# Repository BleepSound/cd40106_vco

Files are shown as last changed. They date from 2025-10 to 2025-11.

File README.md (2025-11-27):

[][cc-by-sa]

# CD40106 VCO

Latest documentation available at https://bleepsound.github.io/modules/

[][cc-by-sa]

[cc-by-sa]: http://creativecommons.org/licenses/by-sa/4.0/
[cc-by-sa-image]: https://licensebuttons.net/l/by-sa/4.0/88x31.png
[cc-by-sa-shield]: https://img.shields.io/badge/License-CC%20BY--SA%204.0-lightgrey.svg

[][cc-by-sa]

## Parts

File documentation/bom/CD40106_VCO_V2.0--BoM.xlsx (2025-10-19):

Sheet: BoM
CD40106_VCO_V2.0 Bill of Materials
Schematic: | CD40106_VCO | Component Groups: | 57
Variant: | default | Component Count: | 118 (1 SMD/ 117 THT)
Revision: | 2.0 | Fitted Components: | 118 (1 SMD/ 117 THT)
Date: | 2025-10-18 | Number of PCBs: | 1
KiCad Version: | 9.0.4-9.0.4-0~ubuntu22.04.1 | Total Components: | 118
Row | Description | References | Value | Quantity Per PCB | Links | Comments
1 | Multilayer Monolithic Ceramic capacitor 50V 10% | C1 | 470pF | 1 | https://www.taydaelectronics.com/capacitors/monolithic-ceramic-capacitor.html
2 | Multilayer Monolithic Ceramic capacitor 50V 10% | C6 C7 | 1nF | 2 | https://www.taydaelectronics.com/capacitors/monolithic-ceramic-capacitor.html
3 | 100V 5% Mylar Film Capacitors | C2 | 2.2nF | 1 | https://www.taydaelectronics.com/capacitors/2-2nf-0-0022uf-100v-5-mylar-film-capacitors.html | If you don't have a mylar capacitor, just use a regular ceramic one
4 | Multilayer Monolithic Ceramic capacitor 50V 10% | C23 | 2.2nF | 1 | https://www.taydaelectronics.com/capacitors/monolithic-ceramic-capacitor.html
5 | Multilayer Monolithic Ceramic capacitor 50V 10% | C4 C5 C12 C13 C14 C15 C16 C17 C18 C19 C20 C21 C22 | 100nF | 13 | https://www.taydaelectronics.com/capacitors/monolithic-ceramic-capacitor.html
6 | Multilayer Monolithic Ceramic capacitor 50V 10% | C3 C8 C9 | 1uF | 3 | https://www.taydaelectronics.com/capacitors/monolithic-ceramic-capacitor.html
7 | 10uF Electrolytic capacitor, 2.0mm pitch, 5mm diameter | C10 C11 | 10uF | 2 | https://www.taydaelectronics.com/capacitors/electrolytic-capacitors.html
8 | Switching Signal Diode 200mA 100V DO-35 | D1 D2 | 1N4148 | 2 | https://www.taydaelectronics.com/1n4148-switching-signal-diode.html
9 | 40V 1A Schottky Barrier Rectifier Diode, DO-41 | D6 D8 | 1N5819 (http://www.vishay.com/docs/88525/1n5817.pdf) | 2 | https://www.taydaelectronics.com/1n5819-schottky-barrier-diode-1a-40v.html
10 | Small Signal Diode 200mA 100V DO-35 | D3 D4 | 1N914 | 2 | https://www.taydaelectronics.com/1n914-small-signal-diode-200ma-100v.html
11 | Alpha/bourns vertical potentiometer | FM_LVL1 | B1M | 1 | https://www.thonk.co.uk/shop/alpha-9mm-pots/
12 | Alpha/bourns vertical potentiometer | Fine1 | B10k | 1 | https://www.thonk.co.uk/shop/alpha-9mm-pots/
13 | Thonkiconn jack | J2 | CV | 1 | https://www.thonk.co.uk/shop/thonkiconn/
14 | 2.54mm pitch pin header vertical 1x2pos | J14 | Conn_01x02 | 1
15 | 2.54mm pitch pin header vertical 1x4pos | J11 | Conn_01x04 | 1
16 | 2.54mm pitch pin socket vertical 1x4pos | J12 | Conn_01x04 | 1
17 | 2.54mm pitch pin socket vertical 1x8pos | J5 J7 | Conn_Circuit | 2
18 | 2.54mm pitch pin header vertical 1x8pos | J6 J8 | Conn_Jack | 2
19 | Thonkiconn jack | J1 | FM | 1 | https://www.thonk.co.uk/shop/thonkiconn/
20 | Thonkiconn jack | J4 | PWM_CV | 1 | https://www.thonk.co.uk/shop/thonkiconn/
21 | Eurorack 10 pin shrouded power header IDC | J16 | Power Input | 1 | https://www.thonk.co.uk/shop/eurorack-diy-essentials/
22 | Thonkiconn jack | J9 | Saw | 1 | https://www.thonk.co.uk/shop/thonkiconn/
23 | Thonkiconn jack | J13 | Sine | 1 | https://www.thonk.co.uk/shop/thonkiconn/
24 | Thonkiconn jack | J10 | Square | 1 | https://www.thonk.co.uk/shop/thonkiconn/
25 | Thonkiconn jack | J3 | Sync | 1 | https://www.thonk.co.uk/shop/thonkiconn/
26 | Thonkiconn jack | J15 | Tri | 1 | https://www.thonk.co.uk/shop/thonkiconn/
27 | Alpha/bourns vertical potentiometer | PWM1 | B100k | 1 | https://www.thonk.co.uk/shop/alpha-9mm-pots/
28 | Alpha/bourns vertical potentiometer | PWM_CV_LVL1 | B250k | 1 | https://www.thonk.co.uk/shop/alpha-9mm-pots/
29 | BC548 NPN General Purpose Transistor | Q2 Q3 | BC548 (https://www.onsemi.com/pub/Collateral/BC550-D.pdf) | 2 | https://www.taydaelectronics.com/bc548-transistor-npn-30v-0-1a.html
30 | BC558 PNP General Purpose Transistor | Q1 Q4 | BC558 (https://www.onsemi.com/pub/Collateral/BC556BTA-D.pdf) | 2 | https://www.taydaelectronics.com/bc558-bc558b-transistor-pnp-0-1a-30v.html
31 | 2.5mm*6.8mm 1/4W 1% Metal film resistor | R15 R29 R36 R41 R44 | 1k | 5 | https://www.taydaelectronics.com/resistors/1-4w-metal-film-resistors/test-group-2.html
32 | 2.5mm*6.8mm 1/4W 1% Metal film resistor | R5 | 1k5 | 1 | https://www.taydaelectronics.com/resistors/1-4w-metal-film-resistors/test-group-2.html
33 | 2.5mm*6.8mm 1/4W 1% Metal film resistor | R47 | 2.2k | 1 | https://www.taydaelectronics.com/resistors/1-4w-metal-film-resistors/test-group-2.html
34 | 2.5mm*6.8mm 1/4W 1% Metal film resistor | R16 R17 R35 | 4.7k | 3 | https://www.taydaelectronics.com/resistors/1-4w-metal-film-resistors/test-group-2.html
35 | 2.5mm*6.8mm 1/4W 1% Metal film resistor | R24 | 9k1 | 1 | https://www.taydaelectronics.com/resistors/1-4w-metal-film-resistors/test-group-2.html
36 | 2.5mm*6.8mm 1/4W 1% Metal film resistor | R20 R21 R22 R23 R25 R26 R34 R37 R48 | 10k | 9 | https://www.taydaelectronics.com/resistors/1-4w-metal-film-resistors/test-group-2.html
37 | 2.5mm*6.8mm 1/4W 1% Metal film resistor | R10 | 14k | 1 | https://www.taydaelectronics.com/resistors/1-4w-metal-film-resistors/test-group-2.html
38 | 2.5mm*6.8mm 1/4W 1% Metal film resistor | R28 R38 R43 R45 | 20k | 4 | https://www.taydaelectronics.com/resistors/1-4w-metal-film-resistors/test-group-2.html
39 | 2.5mm*6.8mm 1/4W 1% Metal film resistor | R18 R19 R40 | 33k | 3 | https://www.taydaelectronics.com/resistors/1-4w-metal-film-resistors/test-group-2.html
40 | 2.5mm*6.8mm 1/4W 1% Metal film resistor | R11 R46 | 47k | 2 | https://www.taydaelectronics.com/resistors/1-4w-metal-film-resistors/test-group-2.html
41 | 2.5mm*6.8mm 1/4W 1% Metal film resistor | R9 R14 | 68k | 2 | https://www.taydaelectronics.com/resistors/1-4w-metal-film-resistors/test-group-2.html
42 | 2.5mm*6.8mm 1/4W 1% Metal film resistor | R1 R2 R3 R4 R7 R8 R12 R13 R31 R42 | 100k | 10 | https://www.taydaelectronics.com/resistors/1-4w-metal-film-resistors/test-group-2.html
43 | 2.5mm*6.8mm 1/4W 1% Metal film resistor | R33 | 130k | 1 | https://www.taydaelectronics.com/resistors/1-4w-metal-film-resistors/test-group-2.html
44 | 2.5mm*6.8mm 1/4W 1% Metal film resistor | R30 R39 | 330k | 2 | https://www.taydaelectronics.com/resistors/1-4w-metal-film-resistors/test-group-2.html
45 | 2.5mm*6.8mm 1/4W 1% Metal film resistor | R27 | 470k | 1 | https://www.taydaelectronics.com/resistors/1-4w-metal-film-resistors/test-group-2.html
46 | 2.5mm*6.8mm 1/4W 1% Metal film resistor | R6 R32 | 1M | 2 | https://www.taydaelectronics.com/resistors/1-4w-metal-film-resistors/test-group-2.html
47 | 6 Position DPST Rotary Switch | SW1 | Octave select switch (https://fr.rs-online.com/web/p/commutateurs-rotatifs/8660278) | 1 | https://uk.rs-online.com/web/p/rotary-switches/8660278?searchId=ac79d3c7-8ed3-428a-a94f-85e7c88d4e39&gb=s | Cut the shaft to required length
48 | Trimmer potentiometer, 25 turn series 3296W | Sine_Bias_trim1 Sine_Shape_trim1 | 100k (https://www.taydaelectronics.com/potentiometer-variable-resistors/cermet-potentiometers/3296w/100k-ohm-trimmer-potentiometer-cermet-25-turns-3296w.html) | 2 | https://www.thonk.co.uk/shop/25-turn-trimmer-potentiometer/
49 | Trimmer potentiometer, 25 turn series 3296W | Sine_Lvl_trim1 | 1M (https://www.taydaelectronics.com/potentiometer-variable-resistors/cermet-potentiometers/3296w/1m-ohm-trimmer-potentiometer-cermet-25-turns-3296w.html) | 1 | https://www.thonk.co.uk/shop/25-turn-trimmer-potentiometer/
50 | 10K NTC type Thermistor | TH1 TH2 TH3 TH4 | Thermistor_NTC - 10k (https://www.taydaelectronics.com/thermistors/10k-ohm-ntc-thermistor-5mm.html) | 4 | https://www.taydaelectronics.com/10k-ohm-ntc-thermistor-5mm.html
51 | Inverters Hex Schmitt Trigger | U2 | CD40106 (https://assets.nexperia.com/documents/data-sheet/HEF40106B.pdf) | 1 | https://eu.mouser.com/ProductDetail/Texas-Instruments/CD40106BE?qs=YhsVCygOPE1CyKyInx%252Bh3Q%3D%3D
52 | Dual Transconductance Amplifiers | U6 | LM13700 (http://www.ti.com/lit/ds/symlink/lm13700.pdf) | 1 | https://eu.mouser.com/c/semiconductors/amplifier-ics/transconductance-amplifiers/?series=LM13700
53 | Adjustable Micropower Voltage Reference Diodes, TO-92 | U3 | LM336-2.5 (http://www.ti.com/lit/ds/symlink/lm185-adj.pdf) | 1 | https://uk.rs-online.com/web/p/voltage-references/5335799P?gb=s
54 | Operational Amplifiers - Op Amps Dual JFET In Low N | U4 U5 | TL072 (http://www.ti.com/lit/ds/symlink/tl071.pdf) | 2 | https://eu.mouser.com/ProductDetail/Texas-Instruments/TL072IP?qs=5BZzbFV4k2v7IBrcArRPQw%3D%3D
55 | Quad Op-Amp | U1 U7 | TL074 (http://www.ti.com/lit/ds/symlink/tl071.pdf) | 2 | https://www.thonk.co.uk/shop/eurorack-diy-essentials/
56 | Trimmer potentiometer, 25 turn series 3296W | lvl_Trim1 | 1k | 1 | https://www.thonk.co.uk/shop/25-turn-trimmer-potentiometer/
57 | Trimmer potentiometer, 25 turn series 3296W | lvl_Trim2 | 2k | 1 | https://www.thonk.co.uk/shop/25-turn-trimmer-potentiometer/

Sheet: Colors
Columns colors
KiCad Fields (default)
Generated Fields
User Fields
Empty Fields

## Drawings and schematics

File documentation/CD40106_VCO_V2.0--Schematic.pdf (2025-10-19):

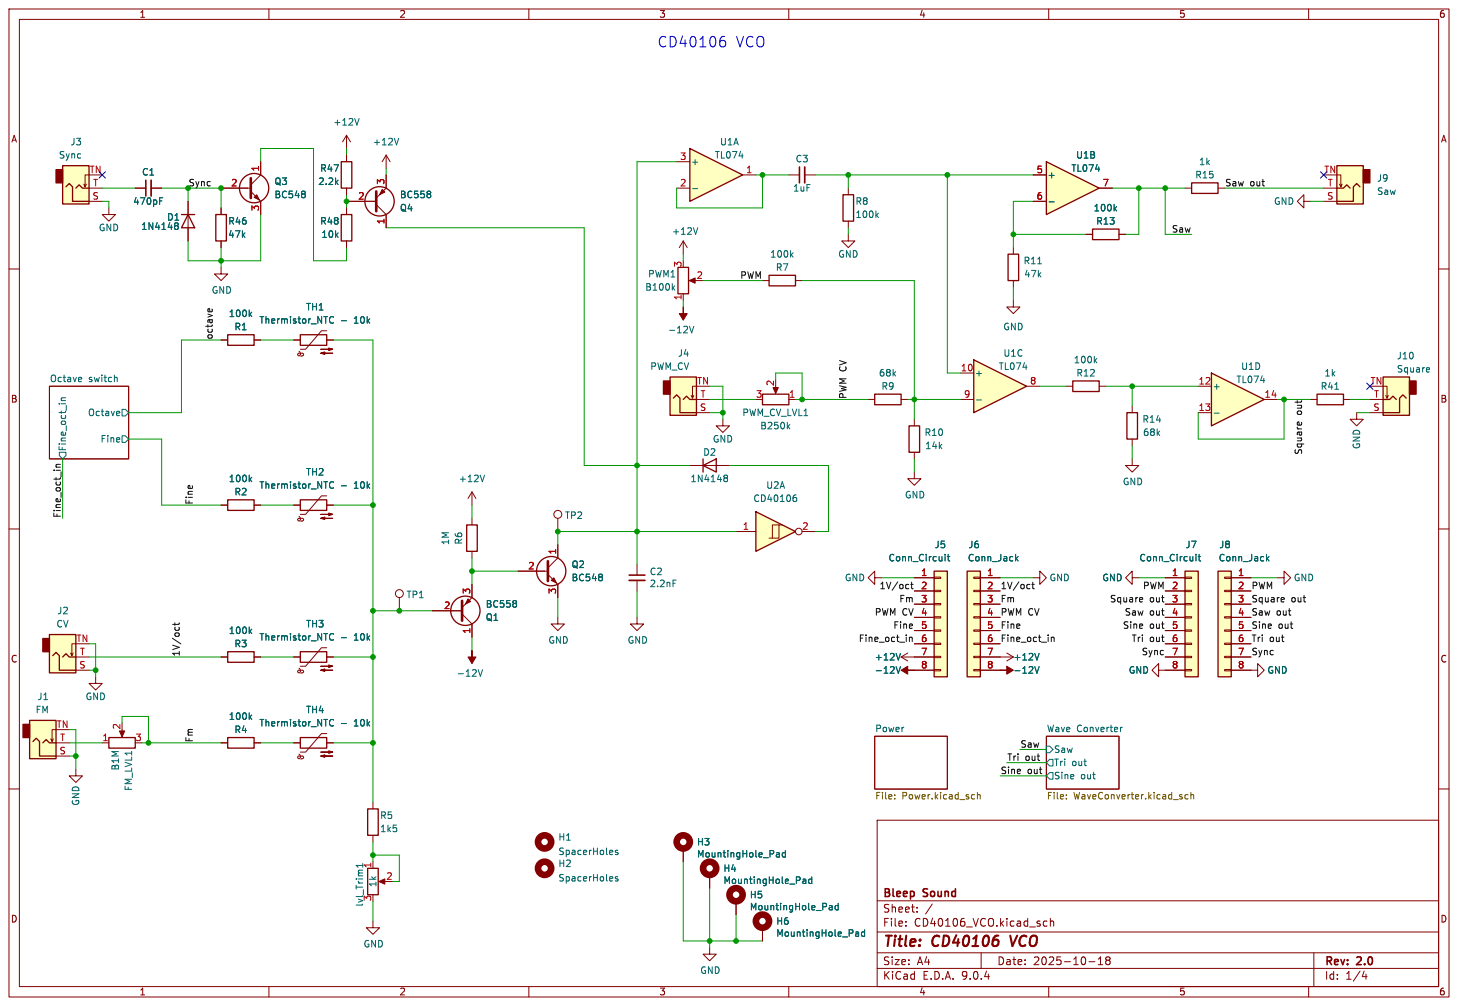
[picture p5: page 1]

Sine out Tri out Saw PWM CV octave

Square outSquare out Fm

Tri out Sine out Wave Converter File: WaveConverter.kicad_sch +12V GND

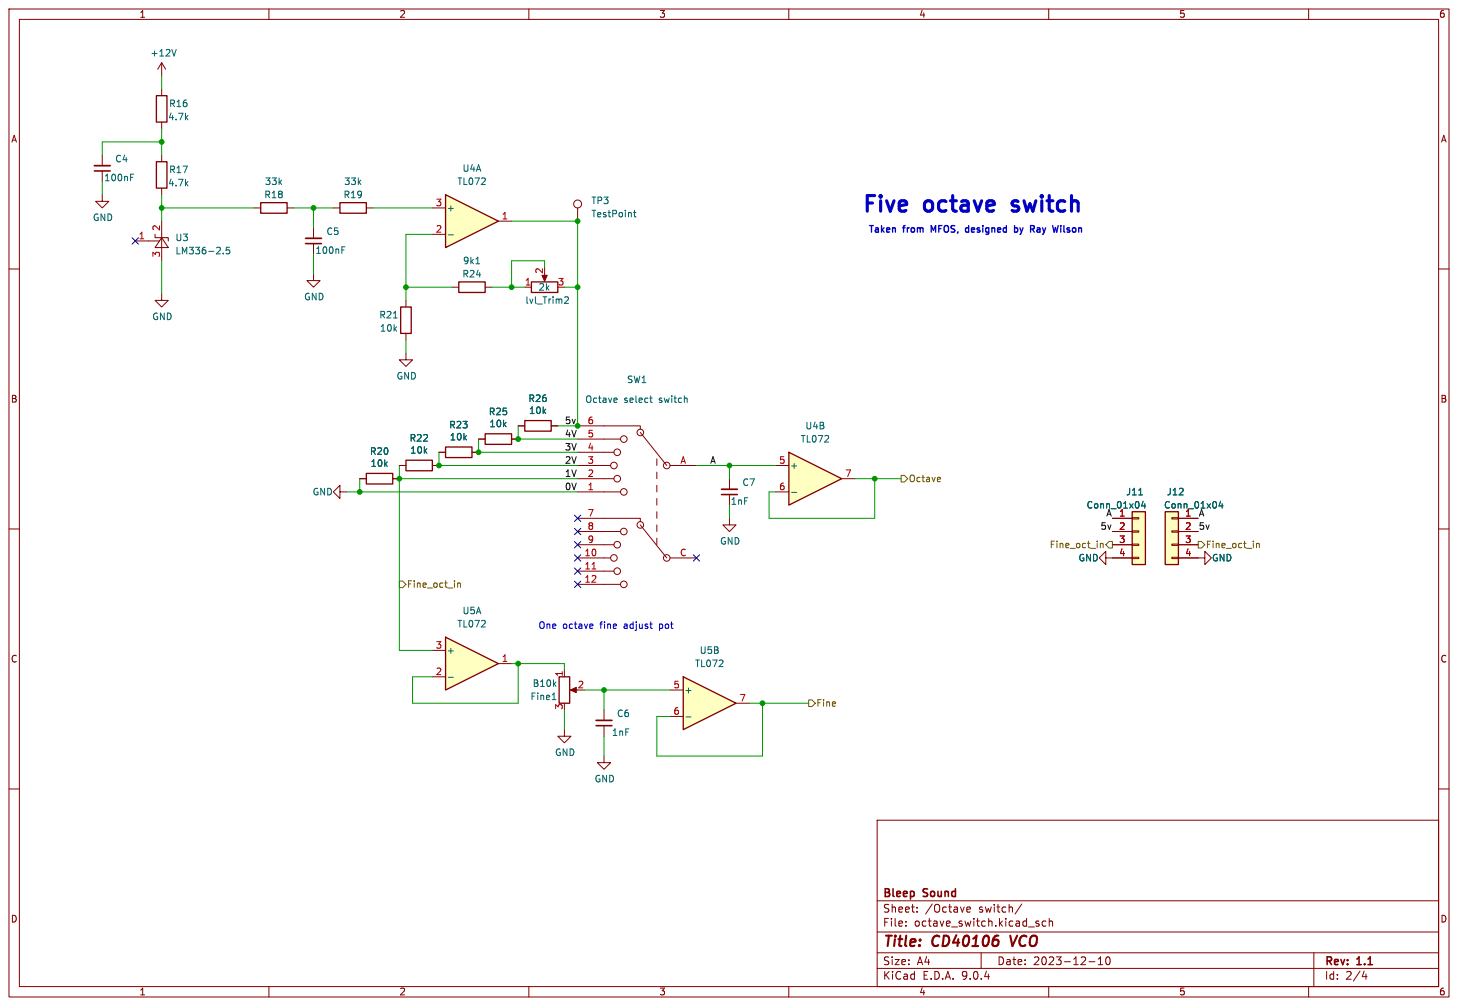
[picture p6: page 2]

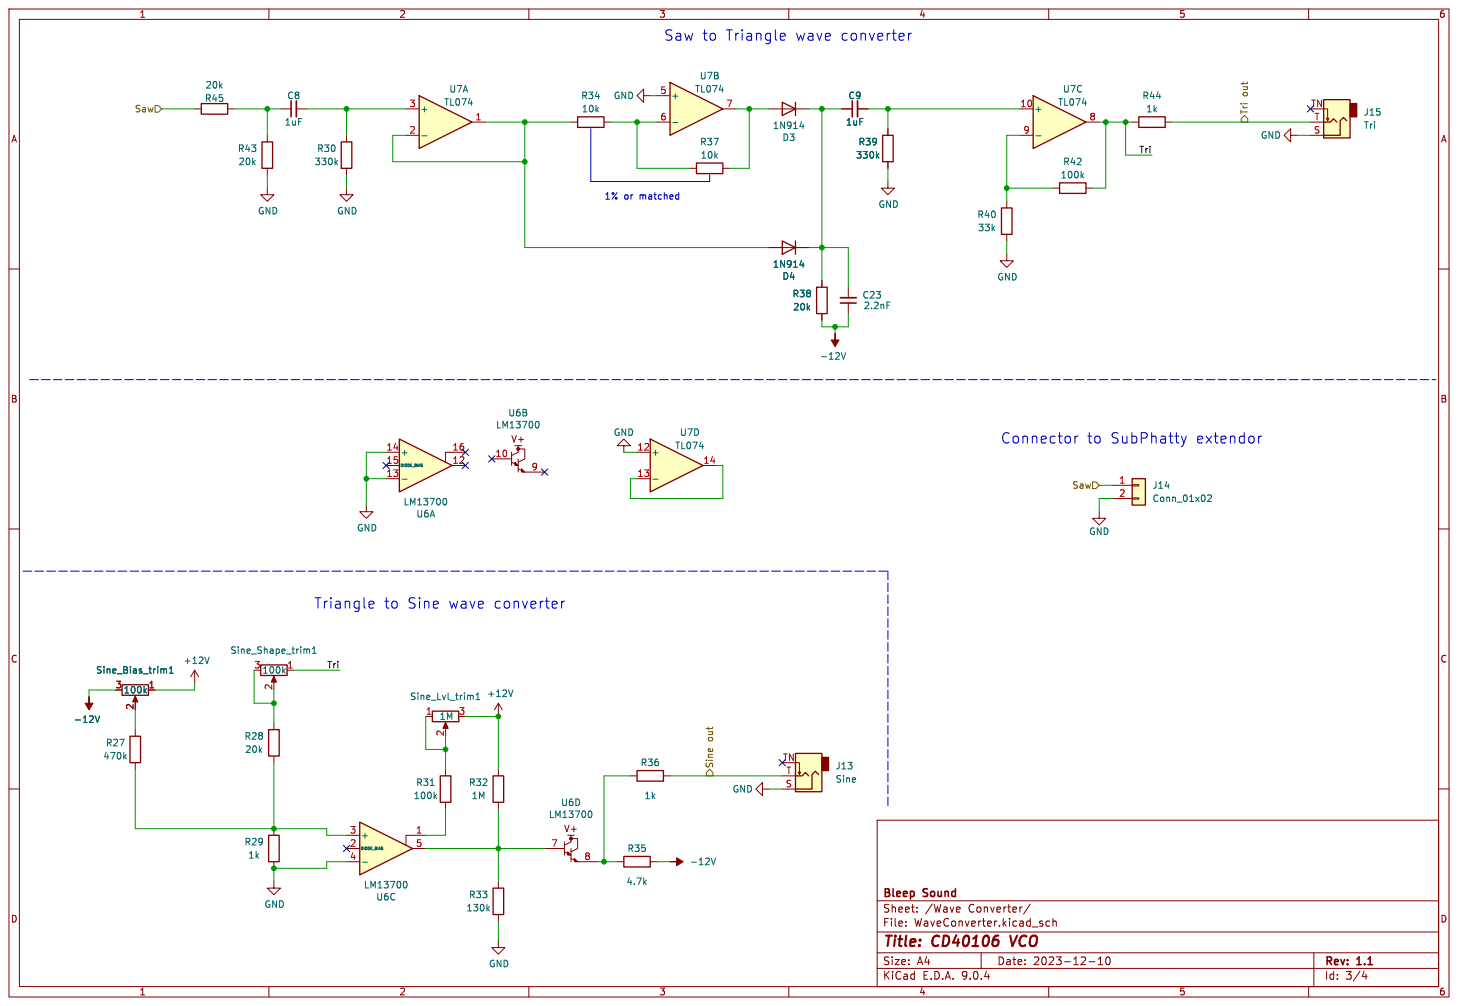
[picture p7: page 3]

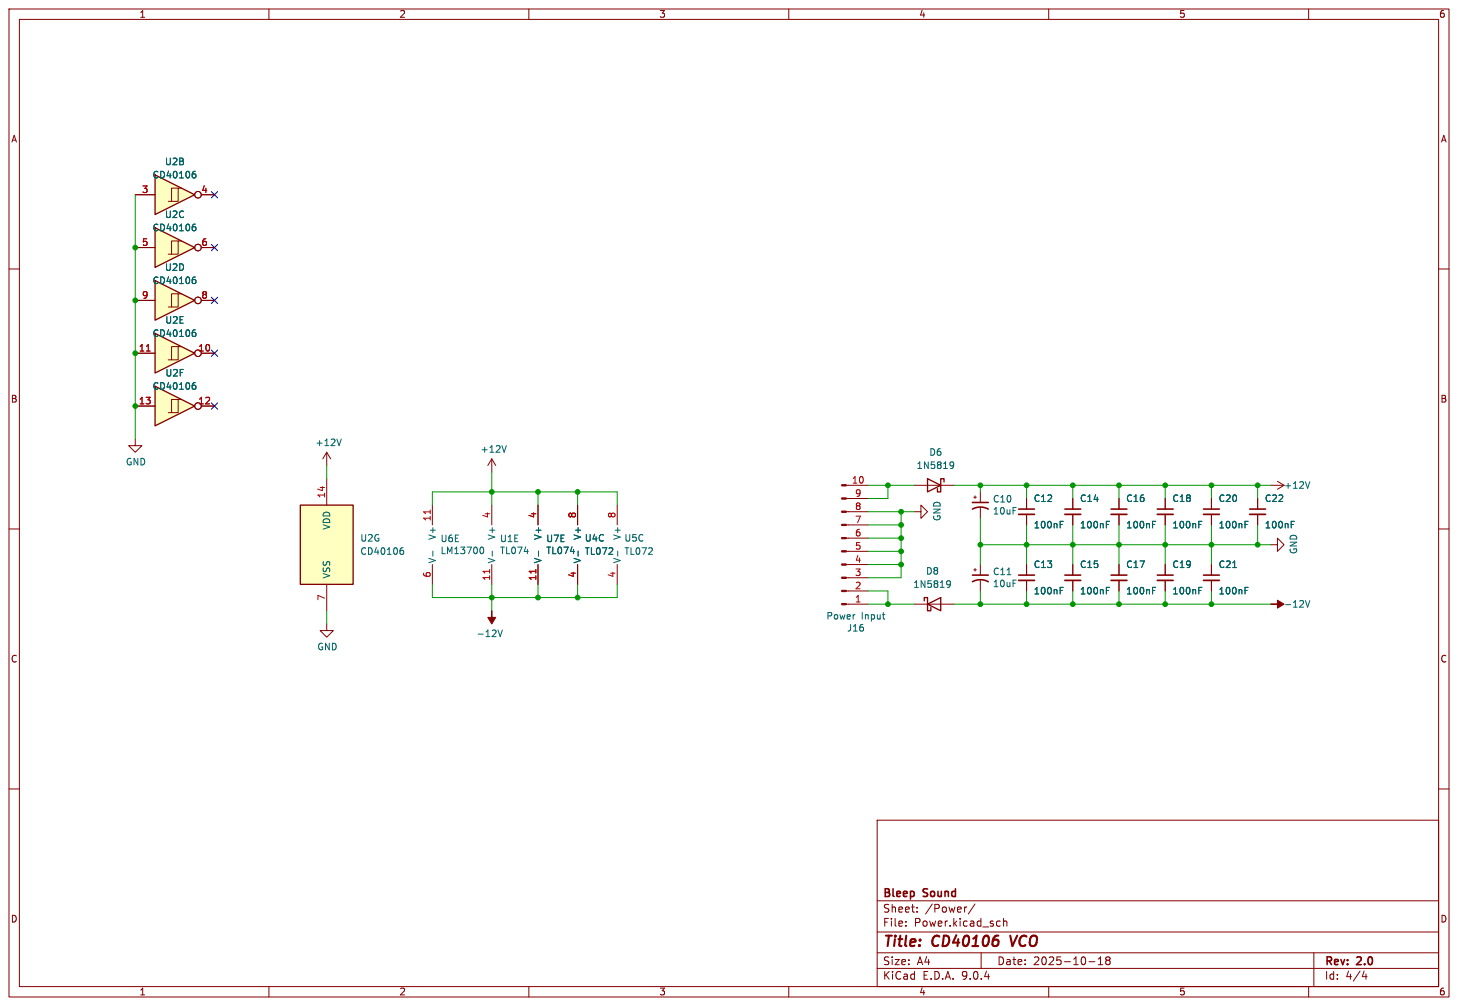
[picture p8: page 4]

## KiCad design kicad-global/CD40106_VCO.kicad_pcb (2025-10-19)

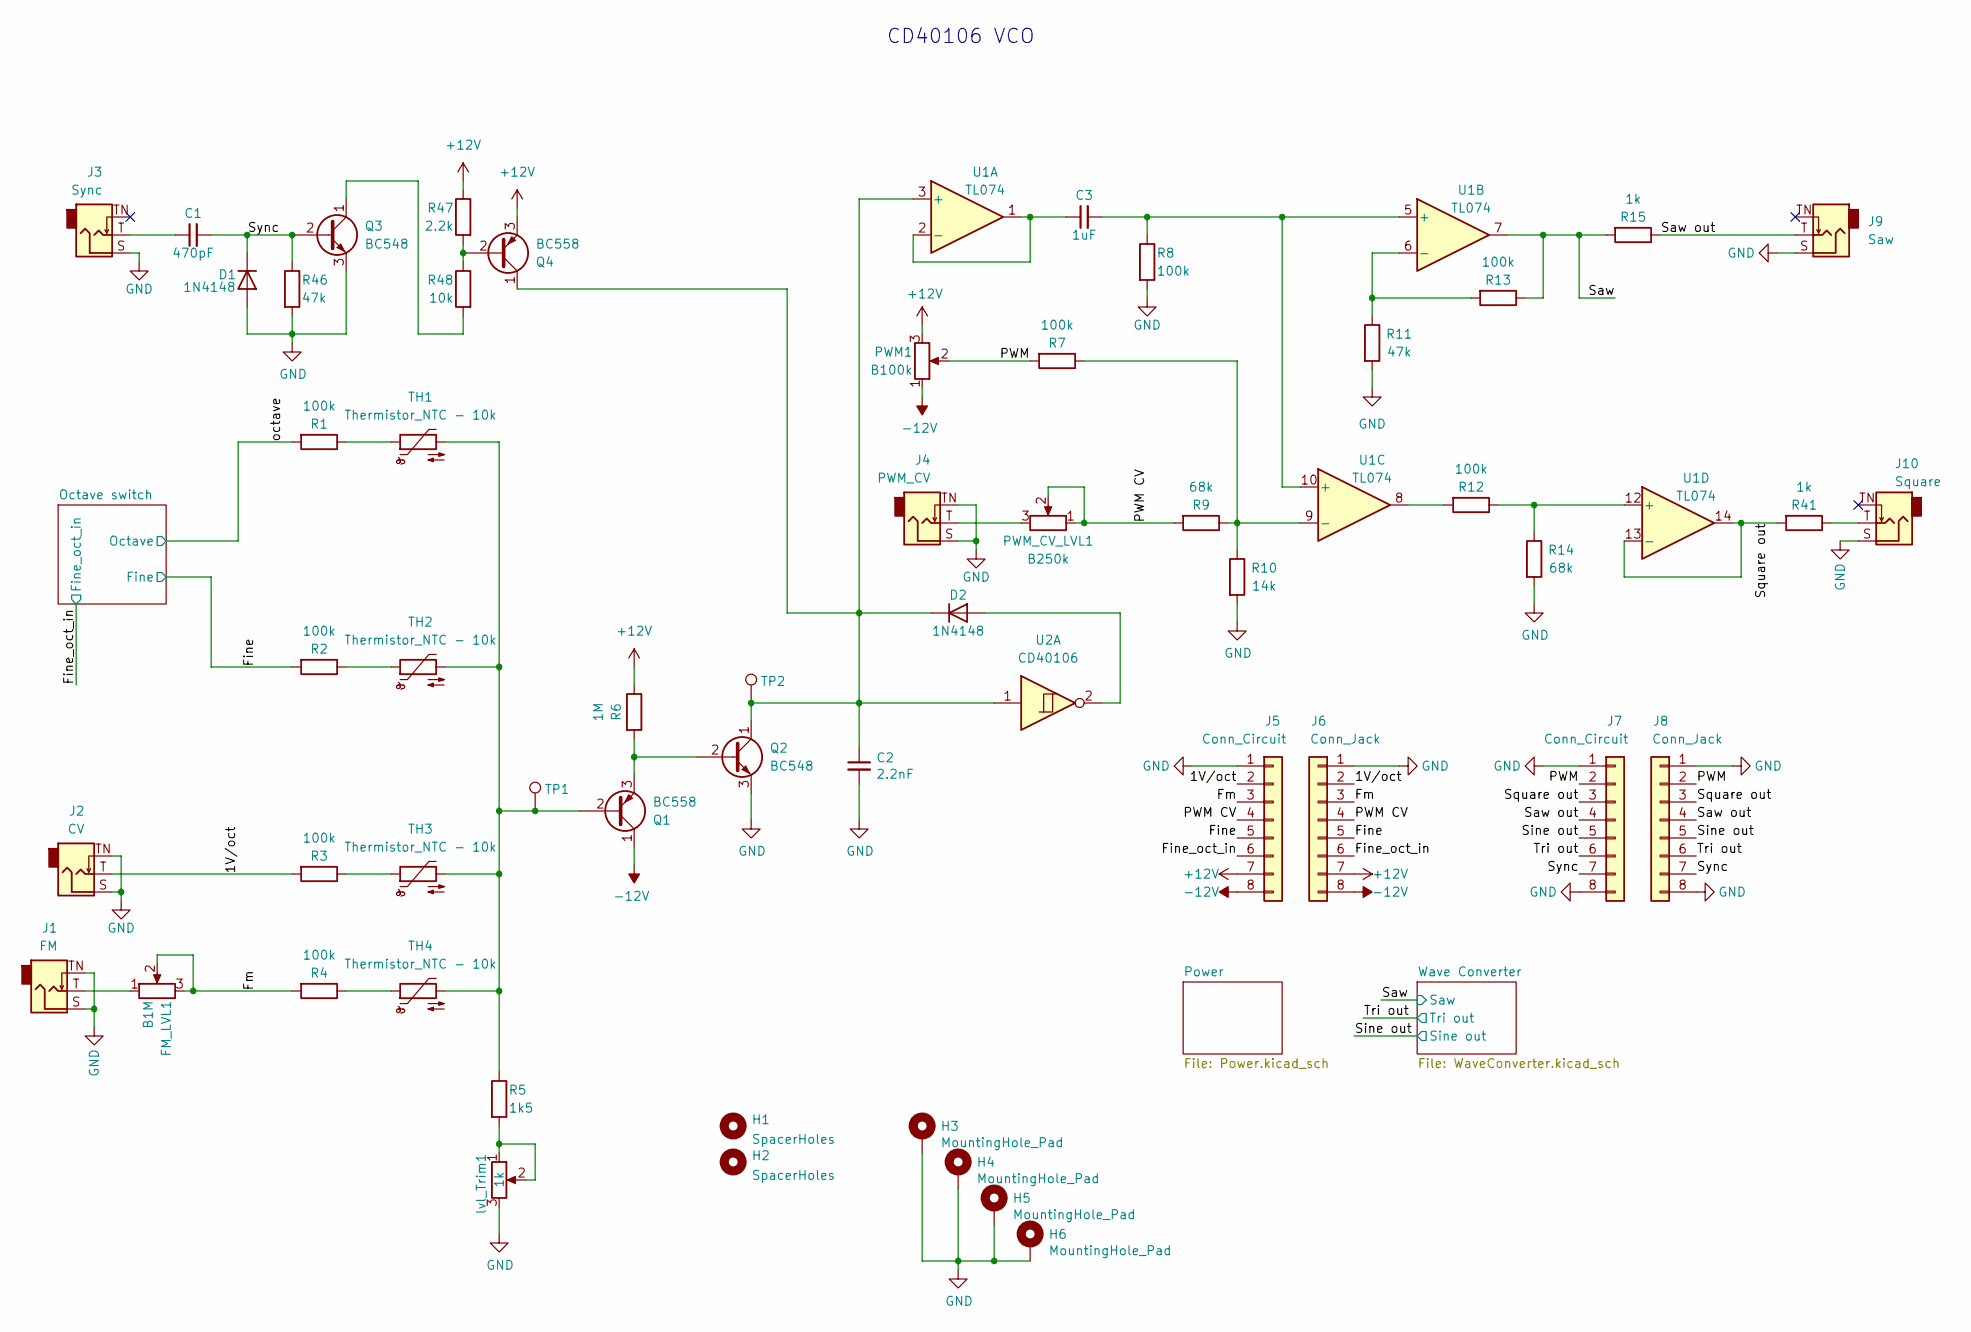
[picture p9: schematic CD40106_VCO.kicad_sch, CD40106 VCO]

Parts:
C1: 470pF; C_Disc_D7.0mm_W2.5mm_P5.00mm
C2: 2.2nF; C_Rect_L7.0mm_W2.5mm_P5.00mm
C3: 1uF; C_Disc_D7.0mm_W2.5mm_P5.00mm
D1, D2: 1N4148; D_DO-35_SOD27_P7.62mm_Horizontal
FM_LVL1: B1M; Pot-bourns-alpha
H1, H2: SpacerHoles; MountingHole_3.2mm_M3
H3, H4, H5, H6: MountingHole_Pad; Doepfer Mounting hole
J1: FM; Thonkiconn
J2: CV; Thonkiconn
J3: Sync; Thonkiconn
J4: PWM_CV; Thonkiconn
J5, J7: Conn_Circuit; PinSocket_1x08_P2.54mm_Vertical
J6, J8: Conn_Jack; PinHeader_1x08_P2.54mm_Vertical
J9: Saw; Thonkiconn
J10: Square; Thonkiconn
PWM1: B100k; Pot-bourns-alpha
PWM_CV_LVL1: B250k; Pot-bourns-alpha
Q1, Q4: BC558; TO-92_Inline
Q2, Q3: BC548; TO-92_Inline
R1, R2, R3, R4, R7, R8, R12, R13: 100k; R_Axial_DIN0207_L6.3mm_D2.5mm_P10.16mm_Horizontal
R5: 1k5; R_Axial_DIN0207_L6.3mm_D2.5mm_P10.16mm_Horizontal
R6: 1M; R_Axial_DIN0207_L6.3mm_D2.5mm_P10.16mm_Horizontal
R9, R14: 68k; R_Axial_DIN0207_L6.3mm_D2.5mm_P10.16mm_Horizontal
R10: 14k; R_Axial_DIN0207_L6.3mm_D2.5mm_P10.16mm_Horizontal
R11, R46: 47k; R_Axial_DIN0207_L6.3mm_D2.5mm_P10.16mm_Horizontal
R15, R41: 1k; R_Axial_DIN0207_L6.3mm_D2.5mm_P10.16mm_Horizontal
R47: 2.2k; R_Axial_DIN0207_L6.3mm_D2.5mm_P10.16mm_Horizontal
R48: 10k; R_Axial_DIN0207_L6.3mm_D2.5mm_P10.16mm_Horizontal
TH1, TH2, TH3, TH4: Thermistor_NTC - 10k; Therm_Disc_D6.5mm_W2.5mm_P3.50mm
TP1, TP2: TestPoint; TestPoint_Plated_Hole_D2.0mm
U1: TL074; DIP-14_W7.62mm_Socket
U2: CD40106; DIP-14_W7.62mm_LongPads
lvl_Trim1: 1k; Potentiometer_Bourns_3296W_Vertical

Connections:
+12V: J5.7, J6.7, PWM1.3, Q4.3 (E), R6.1, R47.1; also elsewhere on the board
-12V: J5.8, J6.8, PWM1.1, Q1.1 (C); also elsewhere on the board
/1V/oct: J2.T, J5.2, J6.2, R3.2
/Fine: J5.5, J6.5, R2.2; also elsewhere on the board
/Fine_oct_in: J5.6, J6.6; also elsewhere on the board
/Fm: FM_LVL1.2, FM_LVL1.3, J5.3, J6.3, R4.2
/PWM: J7.2, J8.2, PWM1.2, R7.2
/PWM CV: J5.4, J6.4, PWM_CV_LVL1.1, PWM_CV_LVL1.2, R9.2
/Saw: R13.1, R15.2, U1.7; also elsewhere on the board
/Saw out: J7.4, J8.4, J9.T, R15.1
/Sine out: J7.5, J8.5; also elsewhere on the board
/Square out: J7.3, J8.3, R41.2, U1.13 (-), U1.14
/Sync: C1.2, D1.1 (K), J7.7, J8.7, Q3.2 (B), R46.1
/Tri out: J7.6, J8.6; also elsewhere on the board
/octave: R1.2; also elsewhere on the board
GND: C2.2, D1.2 (A), H3.1, H4.1, H5.1, H6.1, J1.S, J1.TN, J2.S, J2.TN, J3.S, J4.S, J4.TN, J5.1, J6.1, J7.1, J7.8, J8.1, J8.8, J9.S, J10.S, Q2.3 (E), Q3.3 (E), R8.2, R10.2, R11.2, R14.2, R46.2, lvl_Trim1.3; also elsewhere on the board
unnamed: C1.1, J3.T
unnamed: D2.2 (A), U2.2
unnamed: C2.1, D2.1 (K), Q2.1 (C), Q4.1 (C), TP2.1, U1.3 (+), U2.1
unnamed: FM_LVL1.1, J1.T
unnamed: J4.T, PWM_CV_LVL1.3
unnamed: J10.T, R41.1
unnamed: Q1.2 (B), R5.1, TH1.2, TH2.2, TH3.2, TH4.2, TP1.1
unnamed: Q1.3 (E), Q2.2 (B), R6.2
unnamed: Q3.1 (C), R48.2
unnamed: Q4.2 (B), R47.2, R48.1
unnamed: R1.1, TH1.1
unnamed: R2.1, TH2.1
unnamed: R3.1, TH3.1
unnamed: R4.1, TH4.1
unnamed: R5.2, lvl_Trim1.1, lvl_Trim1.2
unnamed: R12.2, U1.8
unnamed: C3.1, U1.1, U1.2 (-)
unnamed: C3.2, R8.1, U1.5 (+), U1.10 (+)
unnamed: R11.1, R13.2, U1.6 (-)
unnamed: R7.1, R9.1, R10.1, U1.9 (-)
unnamed: R12.1, R14.1, U1.12 (+)

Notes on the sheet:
CD40106 VCO

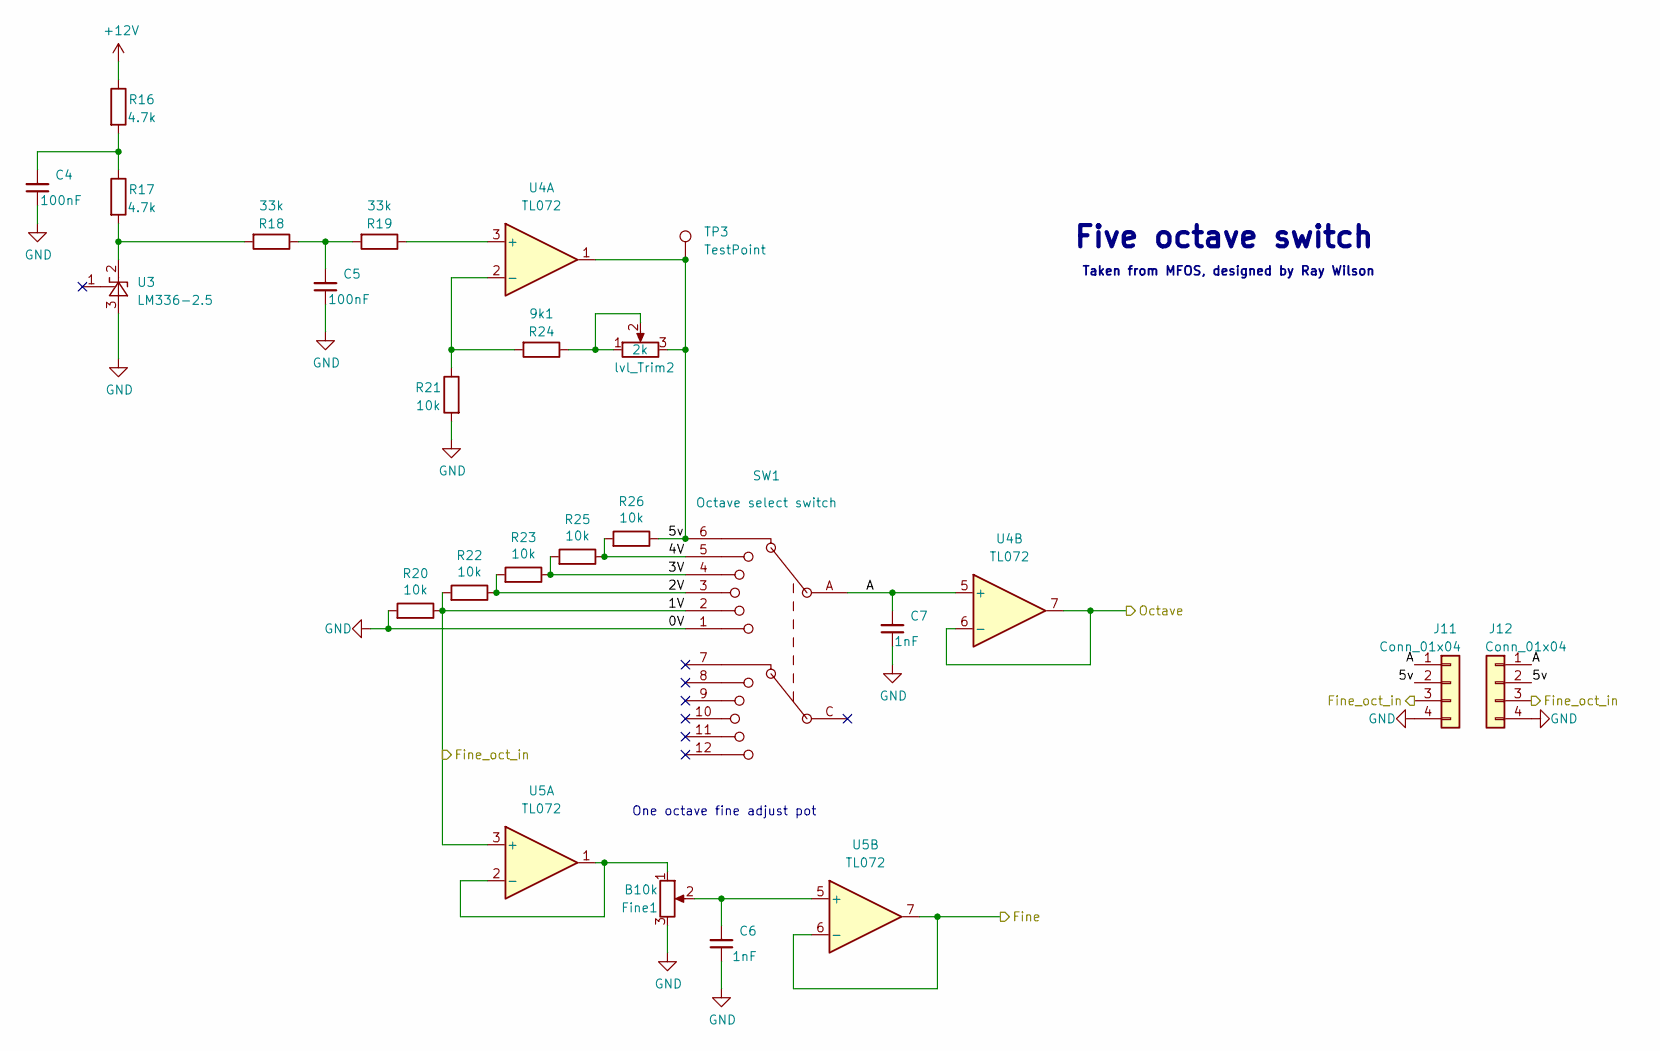
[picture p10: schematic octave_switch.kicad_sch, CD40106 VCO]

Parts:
C4, C5: 100nF; C_Disc_D7.0mm_W2.5mm_P5.00mm
C6, C7: 1nF; C_Disc_D7.0mm_W2.5mm_P5.00mm
Fine1: B10k; Pot-bourns-alpha
J11: Conn_01x04; PinHeader_1x04_P2.54mm_Vertical
J12: Conn_01x04; PinSocket_1x04_P2.54mm_Vertical
R16, R17: 4.7k; R_Axial_DIN0207_L6.3mm_D2.5mm_P10.16mm_Horizontal
R18, R19: 33k; R_Axial_DIN0207_L6.3mm_D2.5mm_P10.16mm_Horizontal
R20, R21, R22, R23, R25, R26: 10k; R_Axial_DIN0207_L6.3mm_D2.5mm_P10.16mm_Horizontal
R24: 9k1; R_Axial_DIN0207_L6.3mm_D2.5mm_P10.16mm_Horizontal
SW1: Octave select switch; CK1055
TP3: TestPoint; TestPoint_Plated_Hole_D2.0mm
U3: LM336-2.5; TO-92_Inline
U4, U5: TL072; DIP-8_W7.62mm_Socket
lvl_Trim2: 2k; Potentiometer_Bourns_3296W_Vertical

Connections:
+12V: R16.1; also elsewhere on the board
/Fine: U5.6 (-), U5.7; also elsewhere on the board
/Fine_oct_in: J11.3, J12.3, R20.1, R22.2, SW1.2, U5.3 (+); also elsewhere on the board
/Octave switch/2V: R22.1, R23.2, SW1.3
/Octave switch/3V: R23.1, R25.2, SW1.4
/Octave switch/4V: R25.1, R26.2, SW1.5
/Octave switch/5v: J11.2, J12.2, R26.1, SW1.6, TP3.1, U4.1, lvl_Trim2.3
/Octave switch/A: C7.2, J11.1, J12.1, SW1.A, U4.5 (+)
/octave: U4.6 (-), U4.7; also elsewhere on the board
GND: C4.1, C5.1, C6.1, C7.1, Fine1.3, J11.4, J12.4, R20.2, R21.2, SW1.1, U3.3 (A); also elsewhere on the board
unnamed: C4.2, R16.2, R17.1
unnamed: C5.2, R18.1, R19.2
unnamed: R24.1, lvl_Trim2.1, lvl_Trim2.2
unnamed: R17.2, R18.2, U3.2 (K)
unnamed: R19.1, U4.3 (+)
unnamed: R21.1, R24.2, U4.2 (-)
unnamed: Fine1.1, U5.1, U5.2 (-)
unnamed: C6.2, Fine1.2, U5.5 (+)

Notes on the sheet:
Five octave switch
Taken from MFOS, designed by Ray Wilson
One octave fine adjust pot

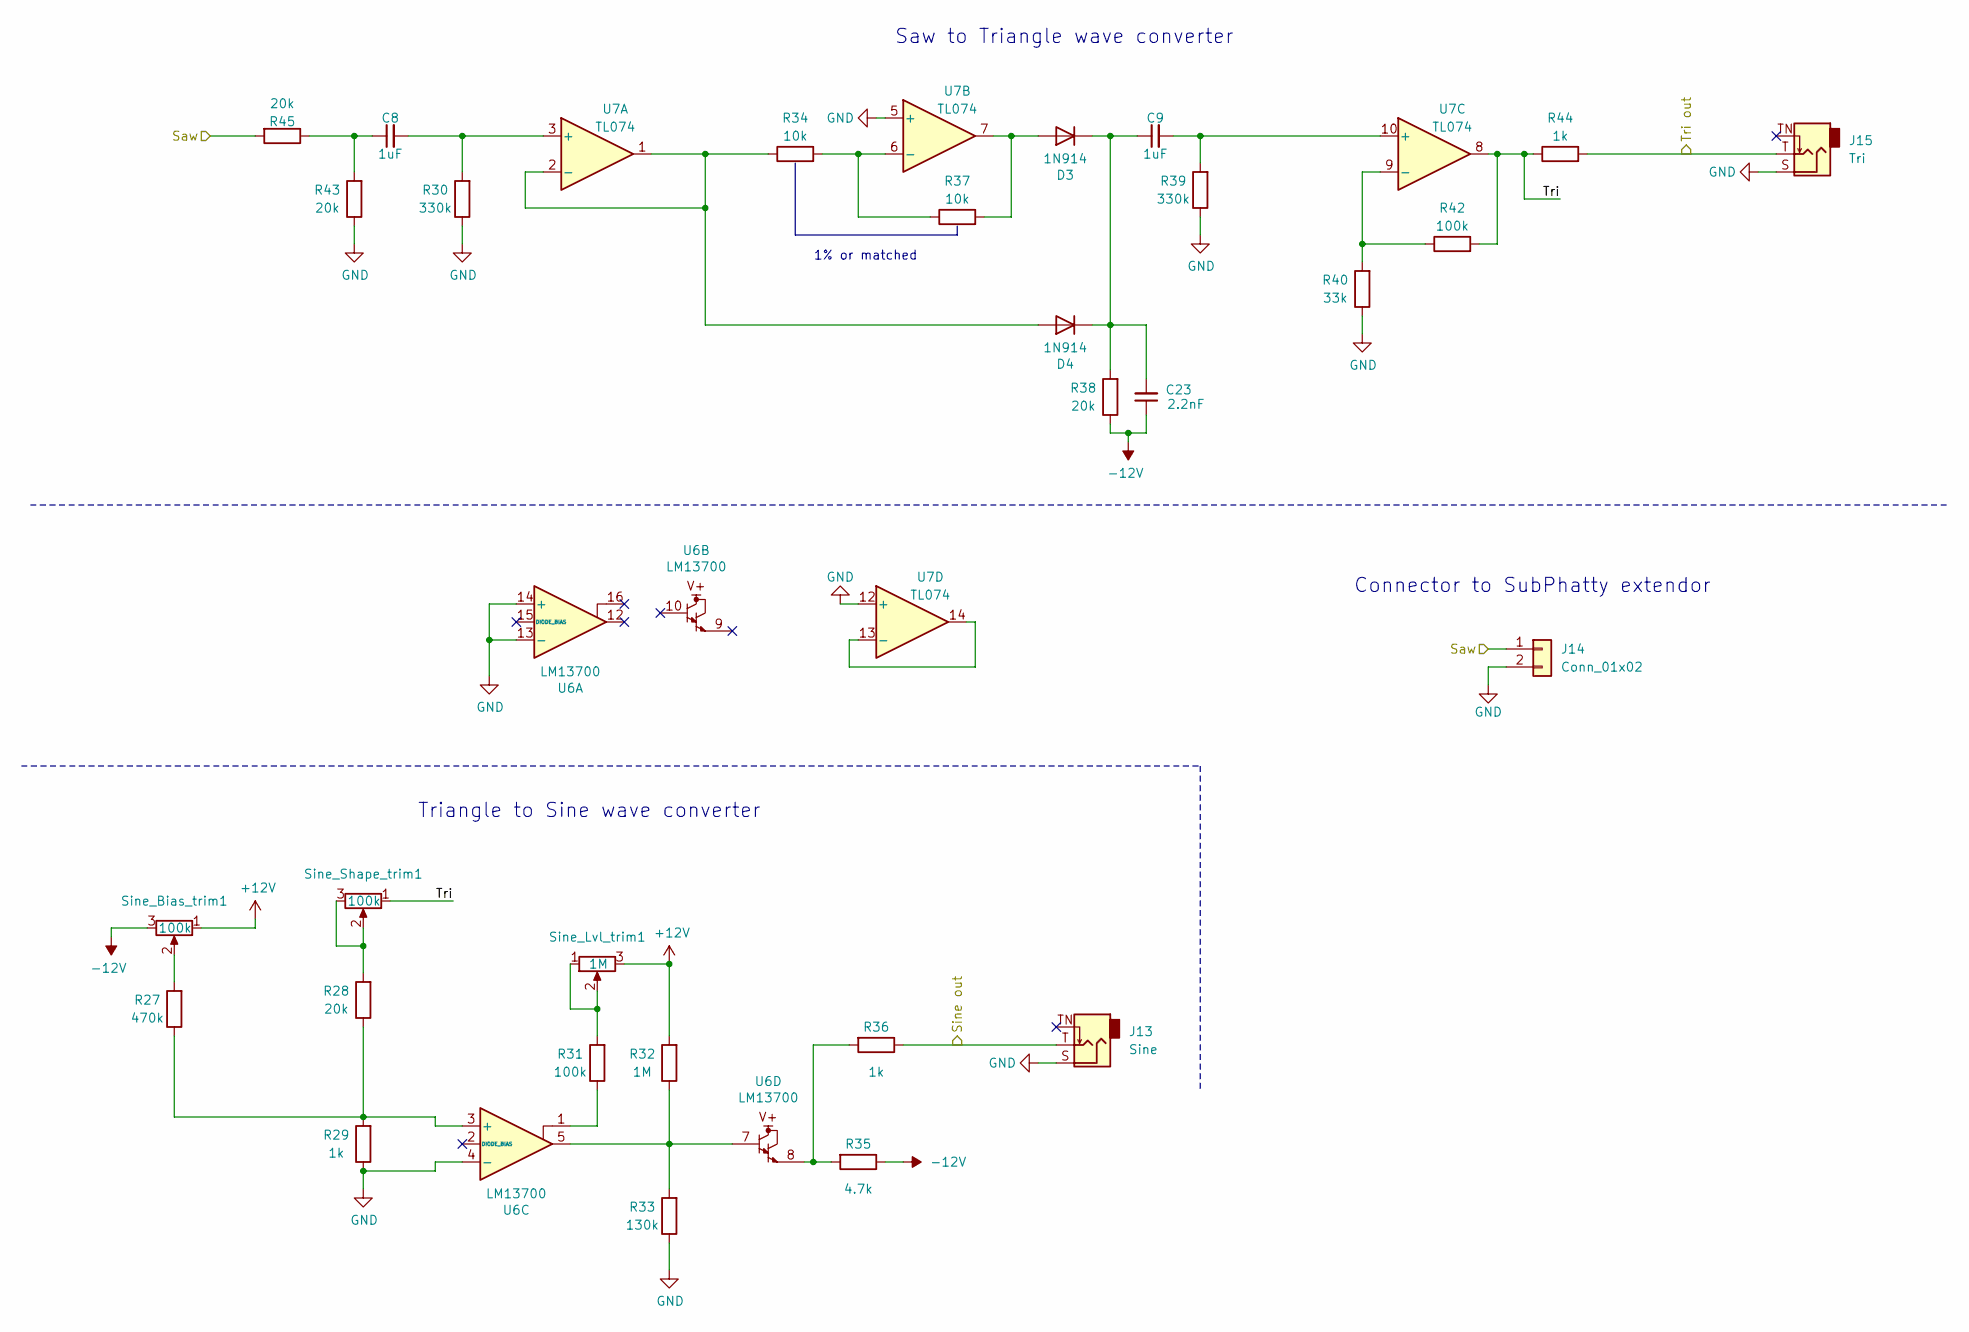
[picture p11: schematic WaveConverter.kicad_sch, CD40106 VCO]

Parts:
C8, C9: 1uF; C_Disc_D7.0mm_W2.5mm_P5.00mm
C23: 2.2nF; C_Disc_D7.0mm_W2.5mm_P5.00mm
D3, D4: 1N914; D_DO-35_SOD27_P7.62mm_Horizontal
J13: Sine; Thonkiconn
J14: Conn_01x02; PinHeader_1x02_P2.54mm_Vertical
J15: Tri; Thonkiconn
R27: 470k; R_Axial_DIN0207_L6.3mm_D2.5mm_P10.16mm_Horizontal
R28, R38, R43, R45: 20k; R_Axial_DIN0207_L6.3mm_D2.5mm_P10.16mm_Horizontal
R29, R36, R44: 1k; R_Axial_DIN0207_L6.3mm_D2.5mm_P10.16mm_Horizontal
R30, R39: 330k; R_Axial_DIN0207_L6.3mm_D2.5mm_P10.16mm_Horizontal
R31, R42: 100k; R_Axial_DIN0207_L6.3mm_D2.5mm_P10.16mm_Horizontal
R32: 1M; R_Axial_DIN0207_L6.3mm_D2.5mm_P10.16mm_Horizontal
R33: 130k; R_Axial_DIN0207_L6.3mm_D2.5mm_P10.16mm_Horizontal
R34, R37: 10k; R_Axial_DIN0207_L6.3mm_D2.5mm_P10.16mm_Horizontal
R35: 4.7k; R_Axial_DIN0207_L6.3mm_D2.5mm_P10.16mm_Horizontal
R40: 33k; R_Axial_DIN0207_L6.3mm_D2.5mm_P10.16mm_Horizontal
Sine_Bias_trim1: 100k; Potentiometer_Bourns_3296W_Vertical
Sine_Lvl_trim1: 1M; Potentiometer_Bourns_3296W_Vertical
Sine_Shape_trim1: 100k; Potentiometer_Bourns_3296W_Vertical
U6: LM13700; SOIC-16_3.9x9.9mm_P1.27mm
U7: TL074; DIP-14_W7.62mm_Socket

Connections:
+12V: R32.2, Sine_Bias_trim1.1, Sine_Lvl_trim1.3; also elsewhere on the board
-12V: C23.1, R35.1, R38.1, Sine_Bias_trim1.3; also elsewhere on the board
/Saw: J14.1, R45.2; also elsewhere on the board
/Sine out: J13.T, R36.1; also elsewhere on the board
/Tri out: J15.T, R44.2; also elsewhere on the board
/Wave Converter/Tri: R42.2, R44.1, Sine_Shape_trim1.1, U7.8
GND: J13.S, J14.2, J15.S, R29.1, R30.1, R33.1, R39.1, R40.1, R43.1, U6.4 (-), U6.13 (-), U6.14 (+), U7.5 (+), U7.12 (+); also elsewhere on the board
unnamed: C8.1, R43.2, R45.1
unnamed: D3.2 (A), R37.2, U7.7
unnamed: C9.1, C23.2, D3.1 (K), D4.1 (K), R38.2
unnamed: D4.2 (A), R34.1, U7.1, U7.2 (-)
unnamed: R27.2, Sine_Bias_trim1.2
unnamed: R28.2, Sine_Shape_trim1.2, Sine_Shape_trim1.3
unnamed: R31.1, U6.1
unnamed: R31.2, Sine_Lvl_trim1.1, Sine_Lvl_trim1.2
unnamed: R32.1, R33.2, U6.5, U6.7
unnamed: R35.2, R36.2, U6.8
unnamed: R27.1, R28.1, R29.2, U6.3 (+)
unnamed: C8.2, R30.2, U7.3 (+)
unnamed: R34.2, R37.1, U7.6 (-)
unnamed: C9.2, R39.2, U7.10 (+)
unnamed: R40.2, R42.1, U7.9 (-)
unnamed: U7.13 (-), U7.14

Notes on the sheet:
Saw to Triangle wave converter
Triangle to Sine wave converter
1% or matched
Connector to SubPhatty extendor

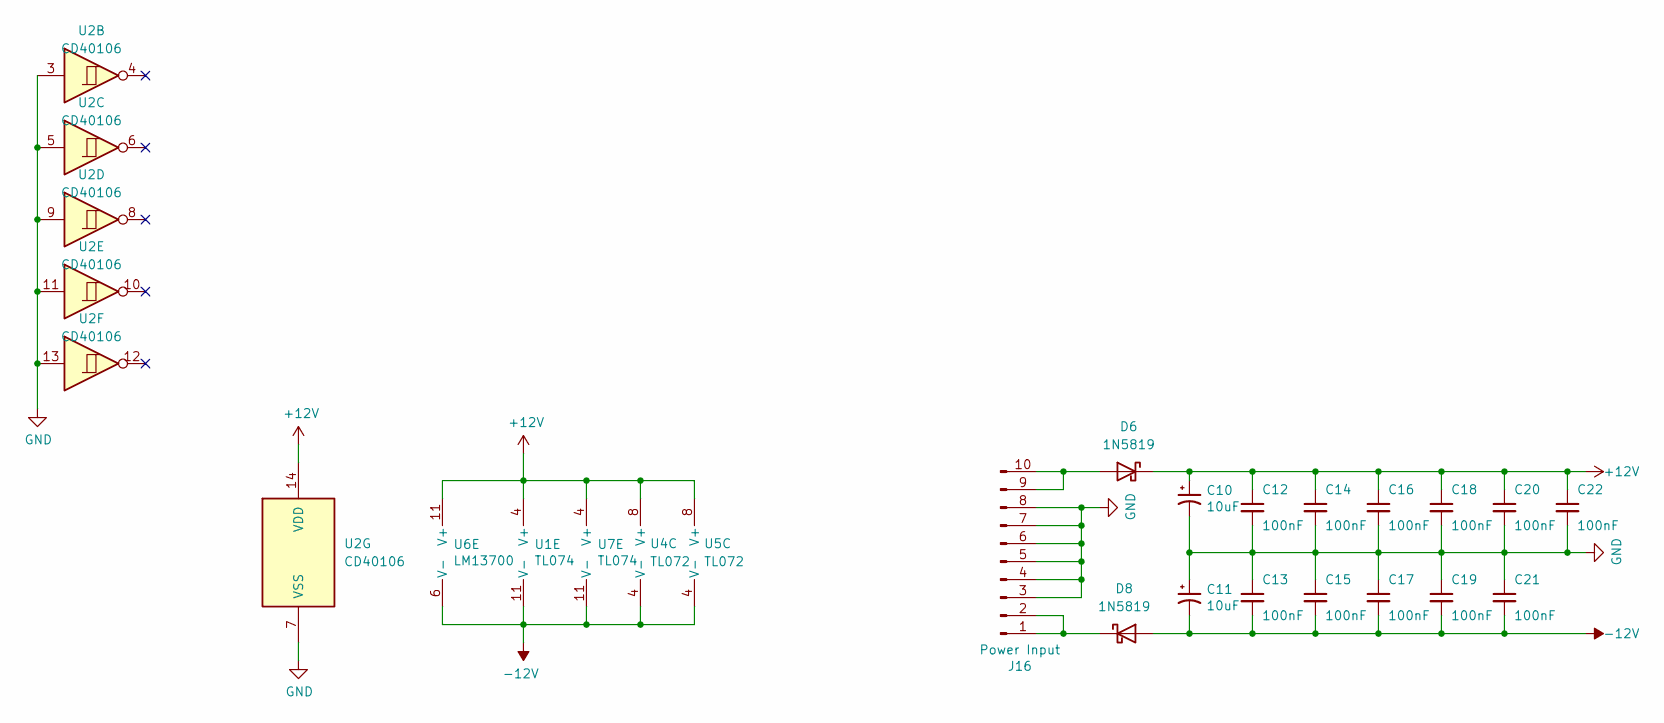
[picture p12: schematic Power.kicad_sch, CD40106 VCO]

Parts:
C10, C11: 10uF; CP_Radial_D5.0mm_P2.00mm
C12, C13, C14, C15, C16, C17, C18, C19, C20, C21, C22: 100nF; C_Disc_D7.0mm_W2.5mm_P5.00mm
D6, D8: 1N5819; D_DO-41_SOD81_P10.16mm_Horizontal
J16: Power Input; IDC-Header_2x05_P2.54mm_Vertical
U1, U7: TL074; DIP-14_W7.62mm_Socket
U2: CD40106; DIP-14_W7.62mm_LongPads
U4, U5: TL072; DIP-8_W7.62mm_Socket
U6: LM13700; SOIC-16_3.9x9.9mm_P1.27mm

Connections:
+12V: C10.1, C12.1, C14.1, C16.1, C18.1, C20.1, C22.1, D6.1 (K), U1.4 (V+), U2.14 (VDD), U4.8 (V+), U5.8 (V+), U6.11 (V+), U7.4 (V+); also elsewhere on the board
-12V: C11.2, C13.2, C15.2, C17.2, C19.2, C21.2, D8.2 (A), U1.11 (V-), U4.4 (V-), U5.4 (V-), U6.6 (V-), U7.11 (V-); also elsewhere on the board
GND: C10.2, C11.1, C12.2, C13.1, C14.2, C15.1, C16.2, C17.1, C18.2, C19.1, C20.2, C21.1, C22.2, J16.3, J16.4, J16.5, J16.6, J16.7, J16.8, U2.3, U2.5, U2.7 (VSS), U2.9, U2.11, U2.13; also elsewhere on the board
unnamed: D6.2 (A), J16.9, J16.10
unnamed: D8.1 (K), J16.1, J16.2

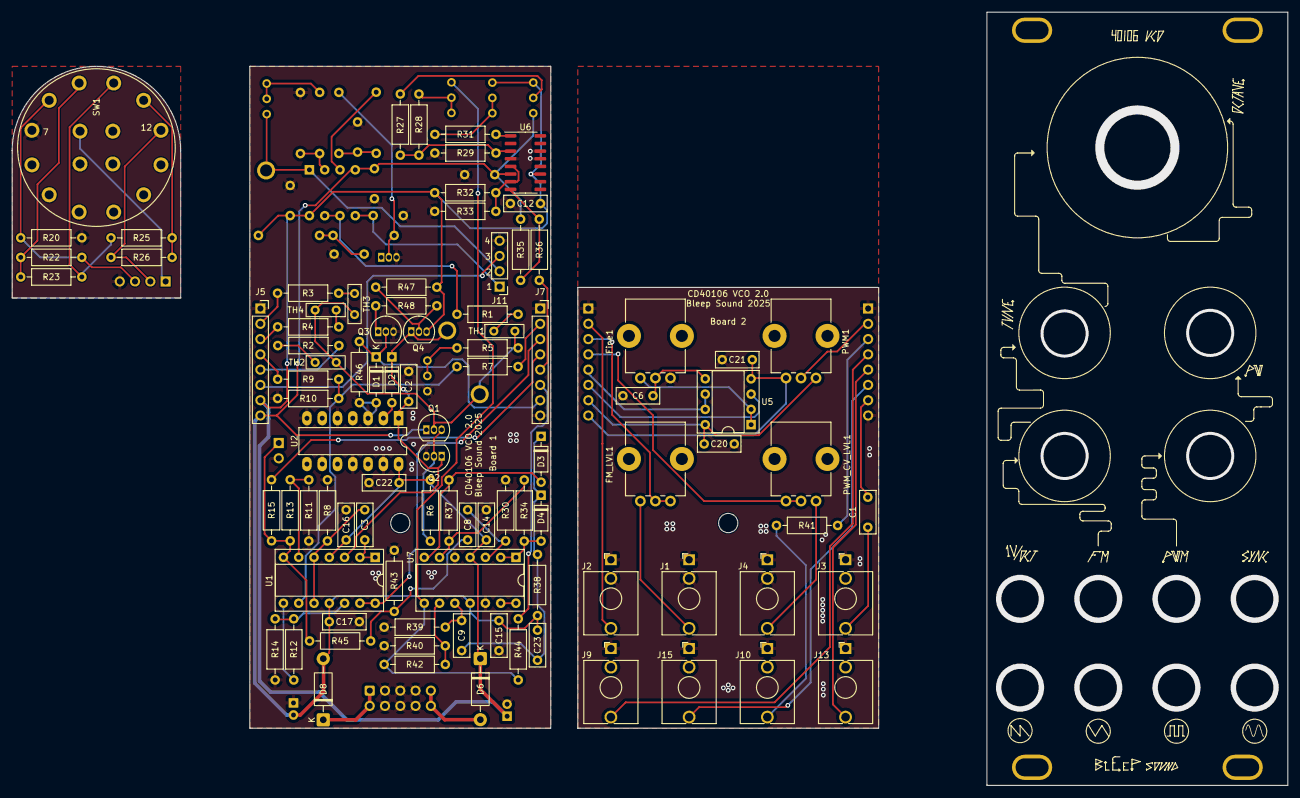
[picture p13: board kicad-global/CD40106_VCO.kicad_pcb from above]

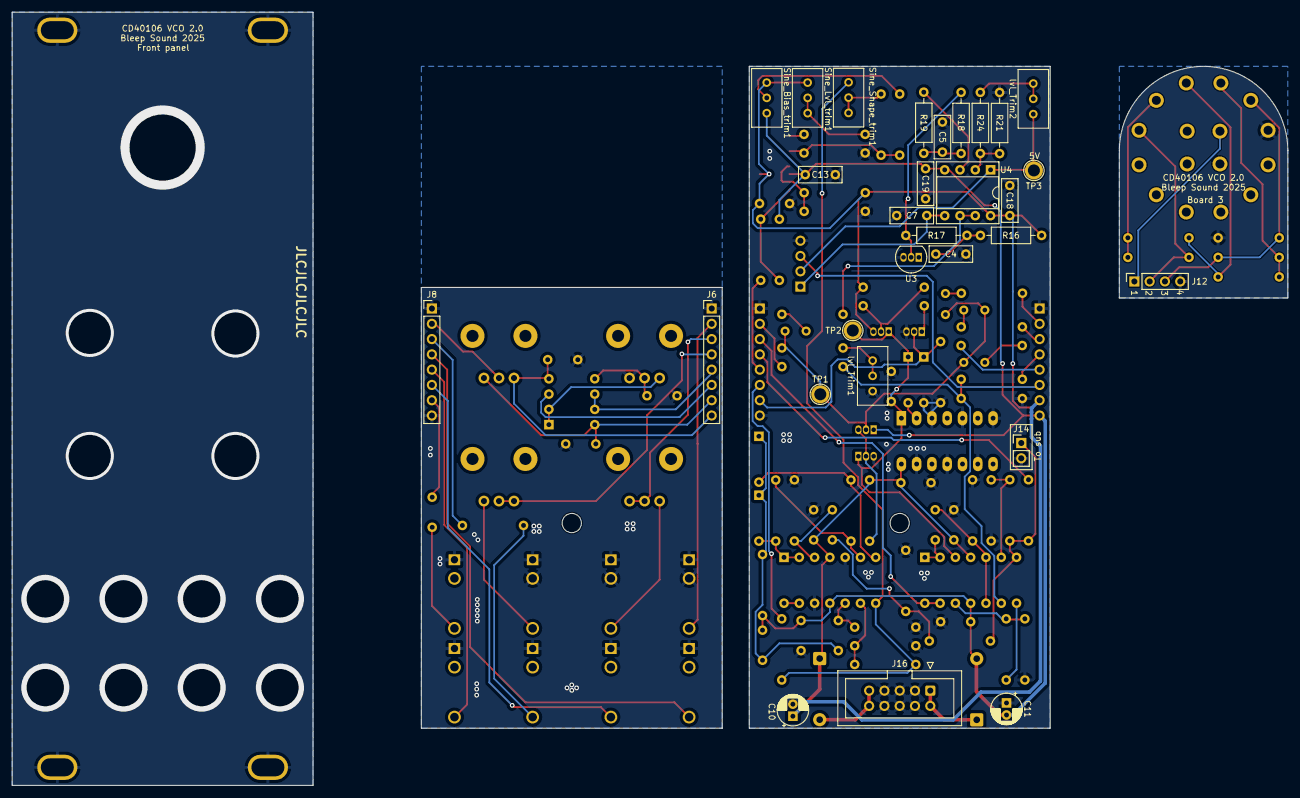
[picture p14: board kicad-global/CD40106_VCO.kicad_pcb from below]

Board: 2 copper layers, 212.0 x 128.5 mm, 127 parts (29 on the bottom side), 69 nets.

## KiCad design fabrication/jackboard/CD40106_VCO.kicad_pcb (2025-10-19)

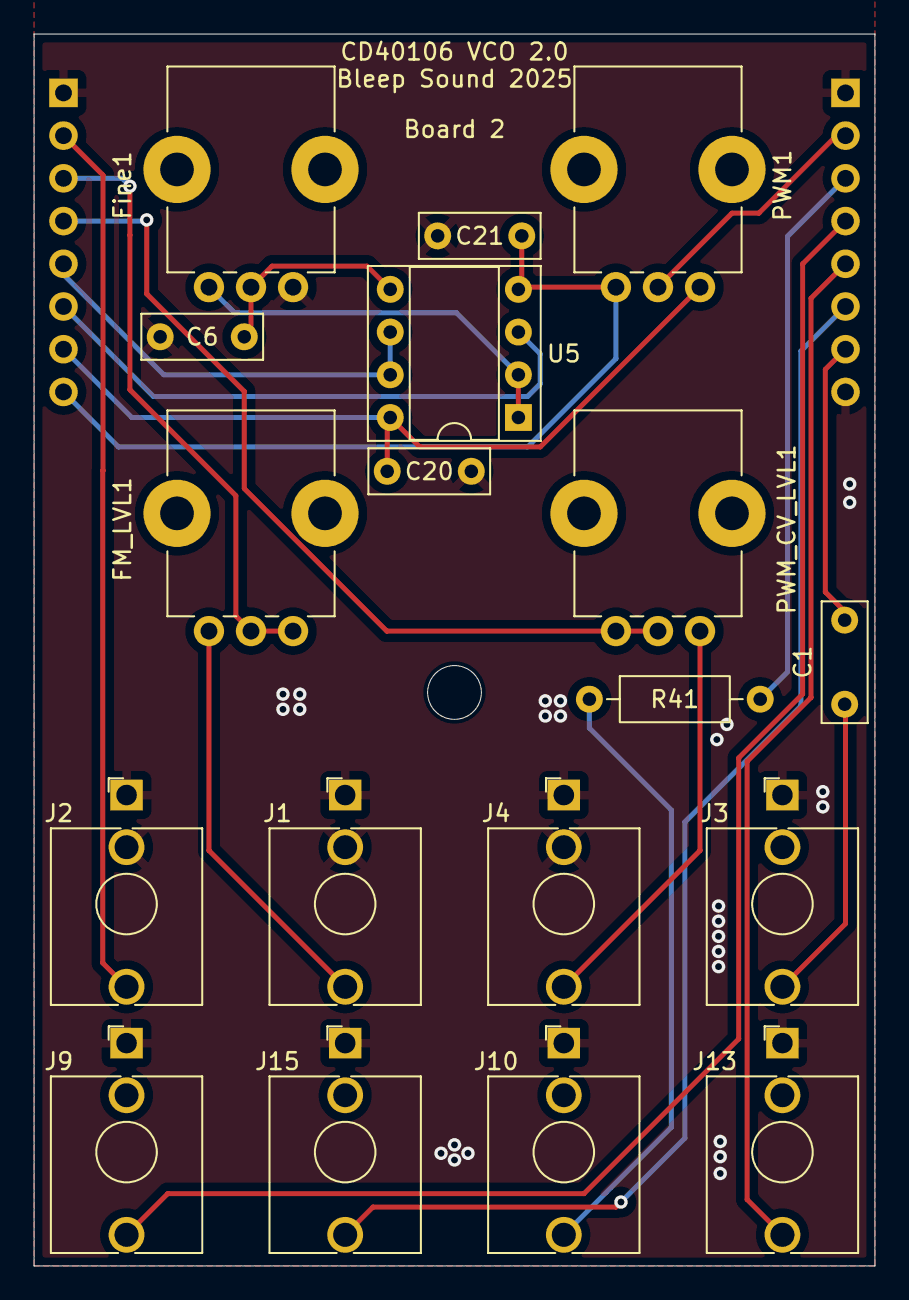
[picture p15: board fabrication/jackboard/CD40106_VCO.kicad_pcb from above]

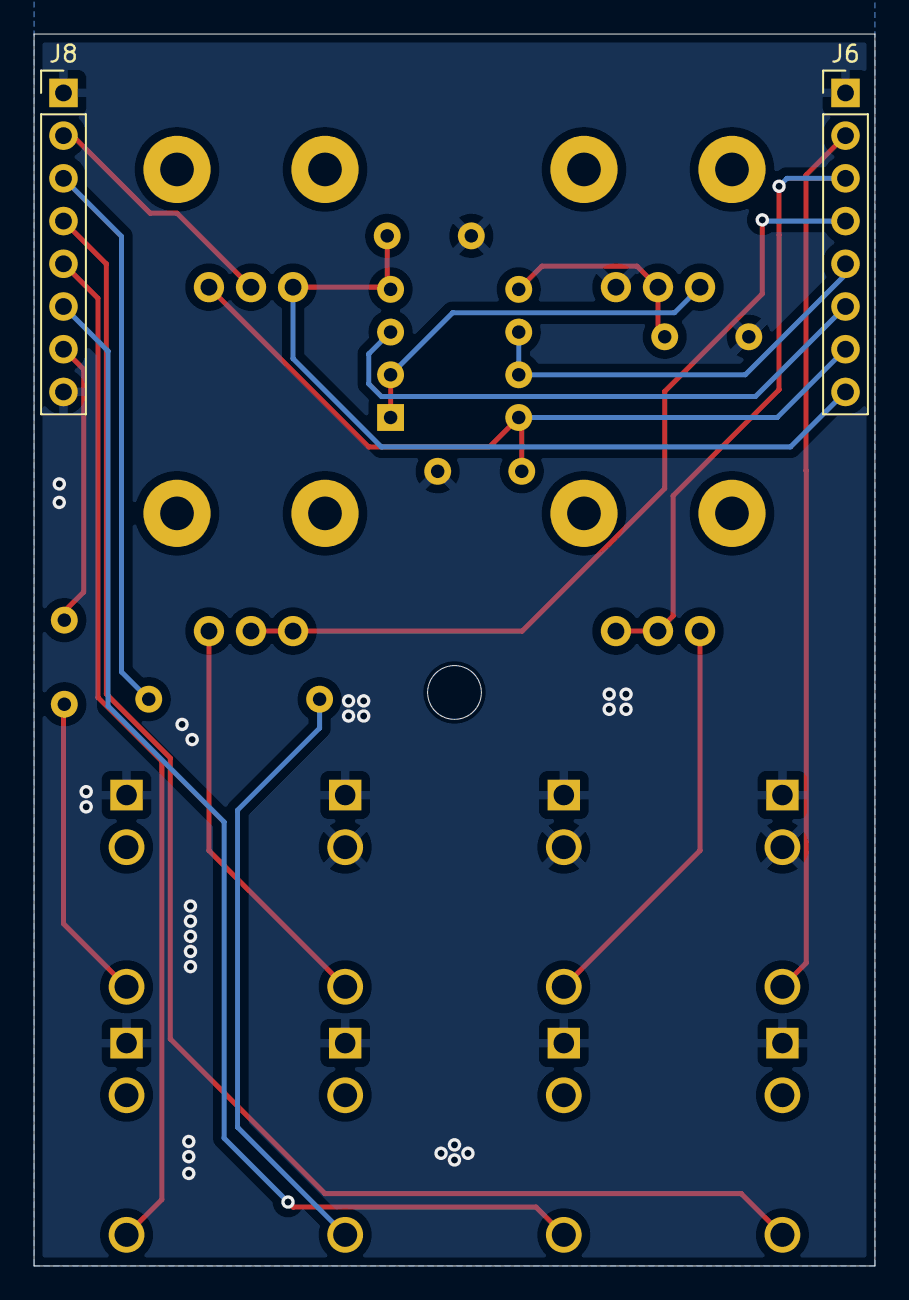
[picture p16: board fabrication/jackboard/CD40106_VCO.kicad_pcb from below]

Board: 2 copper layers, 50.0 x 73.2 mm, 21 parts (2 on the bottom side), 20 nets.

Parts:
C1: 470pF; C_Disc_D7.0mm_W2.5mm_P5.00mm
C6: 1nF; C_Disc_D7.0mm_W2.5mm_P5.00mm
C20, C21: 100nF; C_Disc_D7.0mm_W2.5mm_P5.00mm
FM_LVL1: B1M; Pot-bourns-alpha
Fine1: B10k; Pot-bourns-alpha
H1: SpacerHoles; MountingHole_3.2mm_M3
J1: FM; Thonkiconn
J2: CV; Thonkiconn
J3: Sync; Thonkiconn
J4: PWM_CV; Thonkiconn
J6, J8: Conn_Jack; PinHeader_1x08_P2.54mm_Vertical
J9: Saw; Thonkiconn
J10: Square; Thonkiconn
J13: Sine; Thonkiconn
J15: Tri; Thonkiconn
PWM1: B100k; Pot-bourns-alpha
PWM_CV_LVL1: B250k; Pot-bourns-alpha
R41: 1k; R_Axial_DIN0207_L6.3mm_D2.5mm_P10.16mm_Horizontal
U5: TL072; DIP-8_W7.62mm_Socket

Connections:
+12V: C20.1, J6.7, PWM1.3, U5.8 (V+)
-12V: C21.2, J6.8, PWM1.1, U5.4 (V-)
/1V/oct: J2.T, J6.2
/Fine: J6.5, U5.6 (-), U5.7
/Fine_oct_in: J6.6, U5.3 (+)
/Fm: FM_LVL1.2, FM_LVL1.3, J6.3
/PWM: J8.2, PWM1.2
/PWM CV: J6.4, PWM_CV_LVL1.1, PWM_CV_LVL1.2
/Saw out: J8.4, J9.T
/Sine out: J8.5, J13.T
/Square out: J8.3, R41.2
/Sync: C1.2, J8.7
/Tri out: J8.6, J15.T
GND: C6.1, C20.2, C21.1, Fine1.3, J1.S, J1.TN, J2.S, J2.TN, J3.S, J4.S, J4.TN, J6.1, J8.1, J8.8, J9.S, J10.S, J13.S, J15.S
unnamed: C1.1, J3.T
unnamed: FM_LVL1.1, J1.T
unnamed: J4.T, PWM_CV_LVL1.3
unnamed: J10.T, R41.1
unnamed: Fine1.1, U5.1, U5.2 (-)
unnamed: C6.2, Fine1.2, U5.5 (+)

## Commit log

2023-09-18 initial commit with data
    [CD40106_VCO.kicad_pcb, CD40106_VCO.kicad_sch, PJ301M-12 Thonkiconn v0.2.stp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]
2023-09-20 update components
    [CD40106_VCO.kicad_sch, Power.kicad_sch, WaveConverter.kicad_sch]
2023-12-10 finished v1 of module
    [CD40106_VCO.kicad_pcb, CD40106_VCO.kicad_sch, Power.kicad_sch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]
2023-12-10 add fab files
    [CD40106_VCO.kicad_pcb]
2023-12-10 doc + fab files for V1.0
    [CD40106_VCO--NPTH_map.gbr, CD40106_VCO--PTH_map.gbr, CD40106_VCO-B_Cu.gbl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]
2023-12-10 fix bom link + extra info
2025-10-17 First proto fix
    [CD40106_VCO.kicad_pcb, CD40106_VCO.kicad_sch, Power.kicad_sch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]

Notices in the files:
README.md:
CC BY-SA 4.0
